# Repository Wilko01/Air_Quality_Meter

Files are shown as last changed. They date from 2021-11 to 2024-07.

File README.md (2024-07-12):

# Air_Quality_Meter
By using a 3D printer in house it is important to understand the health impact like micro particles which are generated in the build process of the products that the 3D printer makes. The SDS011 is used to measure the air quality.

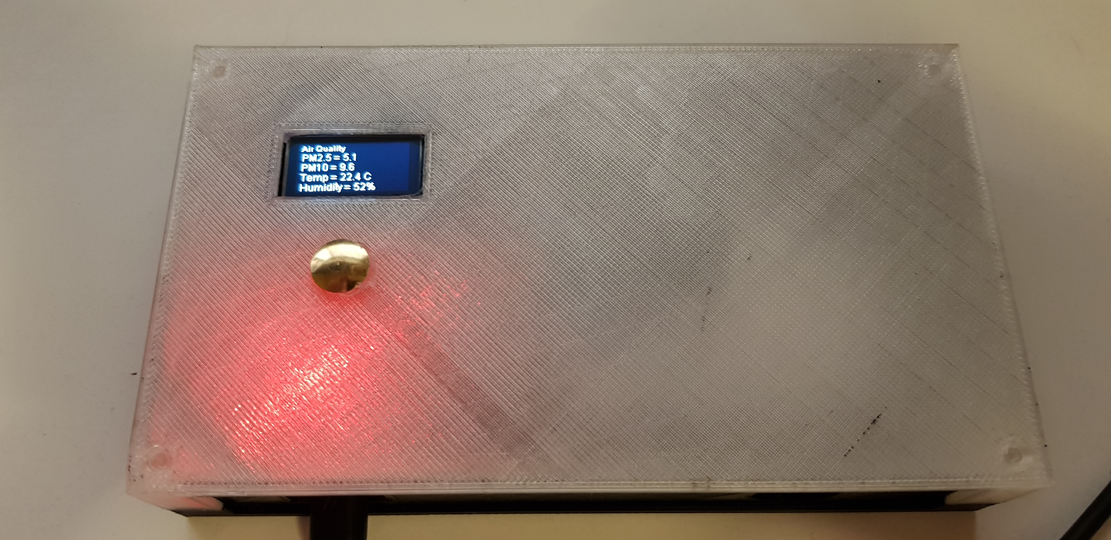
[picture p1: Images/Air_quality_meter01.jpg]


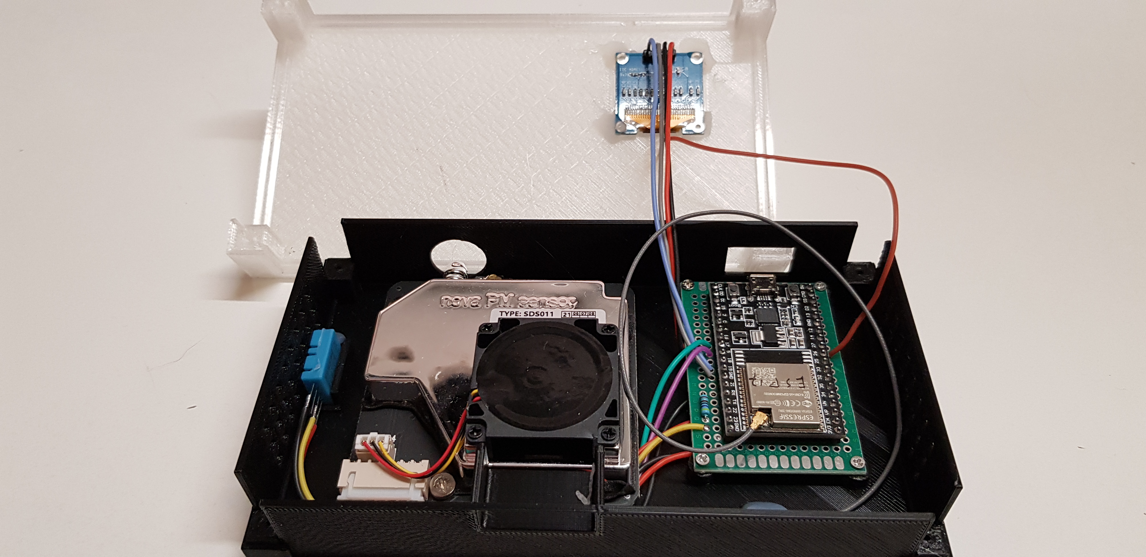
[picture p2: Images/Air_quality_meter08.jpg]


## Description and operation instructions
The SDS011 monitors the air quality by neasuring the 2.5 and 10 um particles in the air. The SDS011 has a lifetime of ~8000 hours, hence the measurement is reduced to periodic measurements. In this case every 10 minutes. The ESP32-WROOM-32U is configured via the ESPHome plugin in Home Assistant. All components are powered via de micro USB connector of the ESP32-WROOM-32U.

 ## Technical description
The SDS011 is connected to the ESP32-WROOM-32D

| SDS101  | ESP32 | SDS1306 | DHT11  | Touch sensor |
| ---|---|---|---|---|
| TX | rx_pin: 16 | | | |
| RX | tx_pin: 17 | | | |
| GND | GND | GND | GND | |
| 5V | 5V | 5V | 5V | |
| | 18 | SDA | | |
| | 19 | SCL | | |
| | 21 | | Signal | |
| | 27 | | | Signal |

### Parts
- 1 x ESP32-WROOM-32U

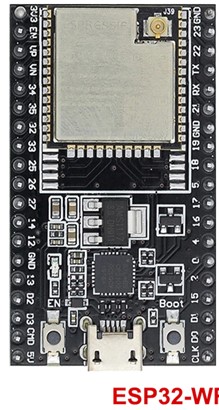
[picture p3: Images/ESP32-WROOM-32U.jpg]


- 1 x 2.4GHz antenna

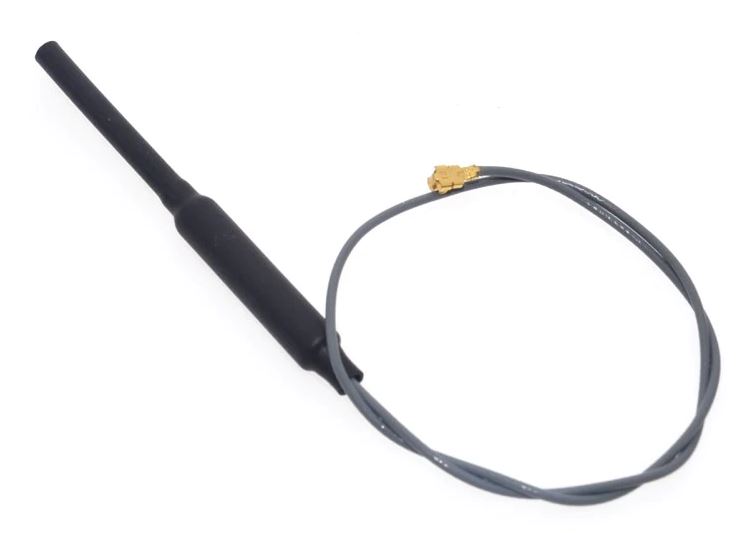
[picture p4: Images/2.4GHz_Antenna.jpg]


- 1 x SDS011

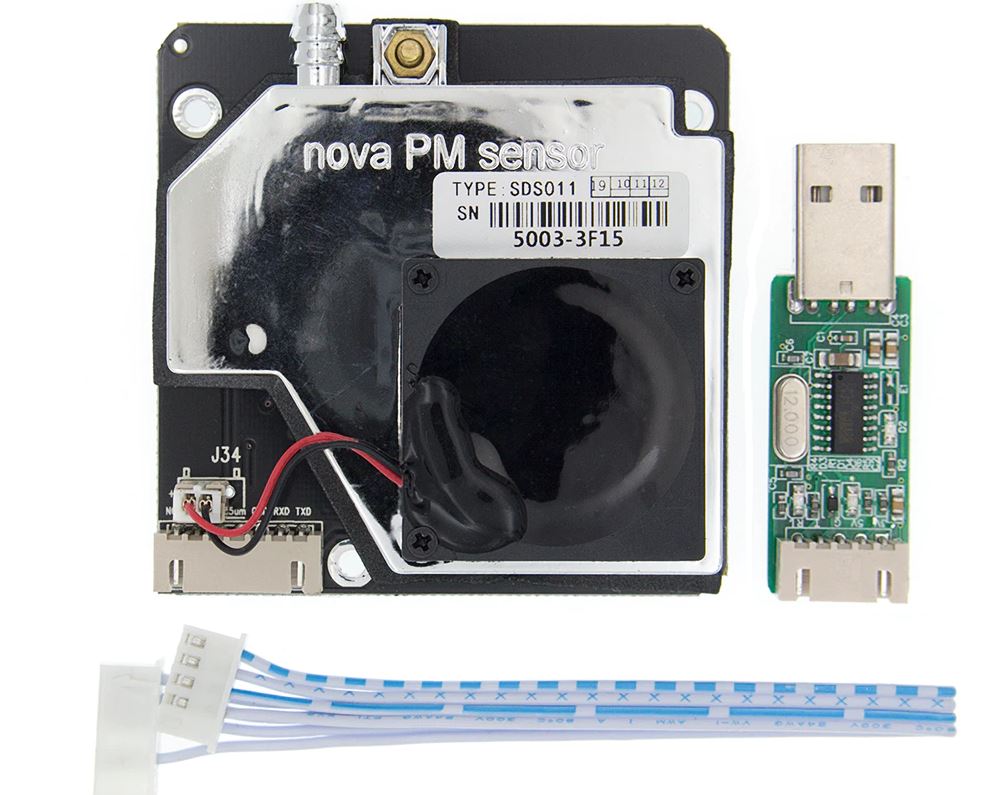
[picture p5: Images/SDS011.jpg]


- 1 x SSD1306 i2C

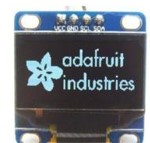
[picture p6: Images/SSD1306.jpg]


- 1 x DHT11

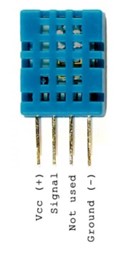
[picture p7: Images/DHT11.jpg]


- 4 x Screws 2.6 x 20 mm
- 1 x thumbtack
- 1 x Micro USB connector

### Schematic overview
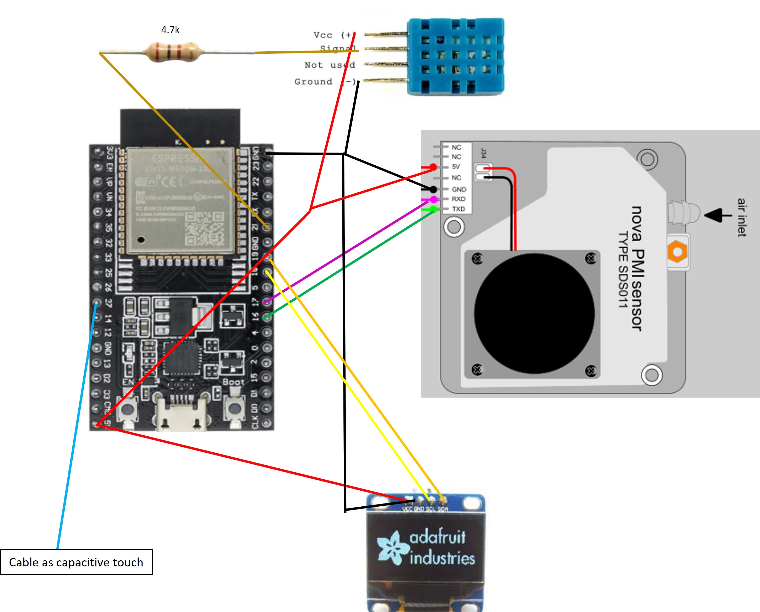
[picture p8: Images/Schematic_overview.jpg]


### ESPHome installation
See the instructions https://github.com/Wilko01/ESPHome  (not listed here)

### ESPHome Configuration in Home Assistant
Create a new device  with this code:
```
# Defining an SDS011 Air Quality Sensor in ESPHome
esphome:
  name: esp17
  platform: ESP32
  board: esp32doit-devkit-v1
  on_boot:
    priority: -100 #lowest priority so start last
    then:
      - lambda: id(display01).turn_off();
#End first code block

# Enable logging
logger:

# Enable Home Assistant API
api:

ota:
  platform: esphome
  password: "4764505ce89048d2422149c83dbc51ca"

wifi:
  ssid: !secret wifi_ssid
  password: !secret wifi_password

  # Enable fallback hotspot (captive portal) in case wifi connection fails
  ap:
    ssid: "Esp17 Fallback Hotspot"
    password: "kWzangCTxyzK"

captive_portal:

# Defining the UART for the SDS011
uart:
  rx_pin: 16
  tx_pin: 17
  baud_rate: 9600

sensor:
  - platform: sds011
    pm_2_5:
      name: "ESP17_Particulates_<2.5µm_Concentration"
      id: pm2_5
    pm_10_0:
      name: "ESP17_Particulates_<10.0µm_Concentration"
      id: pm10_0
    # Set the update interval to balance the accuracy and sensor life
    update_interval: 10min

# Define the temperature and humidity sensor
  - platform: dht
    pin: 21
    temperature:
      name: "ESP17_Temperature"
      id: ESP17_Temperature
    humidity:
      name: "ESP17_Humidity"
      id: ESP17_Humidity
    update_interval: 60s

#specify the connection to the SSD1306
#Connect to the GND and 3,3 but better to 5V
i2c:
  sda: 18
  scl: 19
  scan: true #Will display the i2C address

font:
  - file: 'arial.ttf' #this font file needs to be uploaded to the Home Assistant folder /config/esphome
    id: font1
    size: 10
    
  - file: 'arial.ttf'
    id: font2
    size: 12
    
  - file: 'slkscr.ttf'
    id: font3
    size: 12

esp32_touch:
  setup_mode: false #true shows debug messages in the log and enables to see the intensity of the touch action. 
                   #Make sure to set to false once setup to limit the log spam

binary_sensor:
  - platform: esp32_touch
    name: "ESP17_Touch_Sensor"
    pin: GPIO27
    threshold: 400
    on_release:
      - lambda: id(display01).turn_on();
      - delay: 60s
      - lambda: id(display01).turn_off();

display:
  - platform: ssd1306_i2c
    model: "SSD1306 128x64"
    id: display01
    reset_pin: 0
    address: 0x3C
    contrast: 100%
#Make sure that any comment in the lambda code block is started with // as all
#  code in the block is C++.
    lambda: |-
      it.printf(5, 0, id(font1), "Air Quality");
      if (id(pm2_5).has_state()) {
        it.printf(5, 12, id(font2), "PM2.5 = %.1f", id(pm2_5).state);
      }
      if (id(pm10_0).has_state()) {
        it.printf(5, 25, id(font2), "PM10 = %.1f", id(pm10_0).state);
      }
      if (id(ESP17_Temperature).has_state()) {
        it.printf(5, 38, id(font2), "Temp = %.1f C", id(ESP17_Temperature).state);
      }
      if (id(ESP17_Humidity).has_state()) {
        it.printf(5, 51, id(font2), "Humidity = %.0f%%", id(ESP17_Humidity).state);
      }
#Print the text at column 64 and row 31
#end code

```

### Interface
#### Home Assistant
Home Assistant is connected via the ESPHome integration. The hazardous values for the 2.5um are different from the values of the 10.0um. Therefore two cards are made in the dashboard.

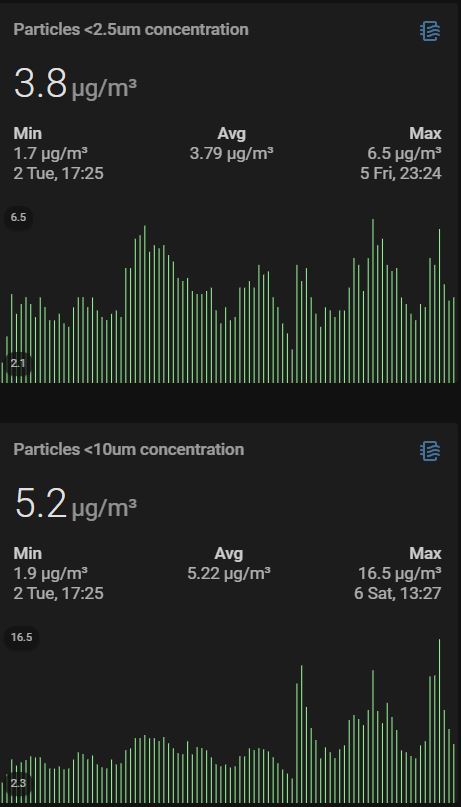
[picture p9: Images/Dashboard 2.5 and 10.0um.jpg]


##### 2.5um card
Create a card in the dashboard of Home Assistant with this code for the 2.5um measurement:
```
type: entities
style:
  .: |
    ha-card {
      --ha-card-box-shadow: none;
      background-color: transparent;
      border-radius: none;

    }
entities:
  - type: custom:mini-graph-card
    entities:
      - entity: sensor.particulates_2_5um_concentration
    icon: mdi:air-filter
    height: 200
    hours_to_show: 96
    more_info: false
    hour24: true
    points_per_hour: 6
    aggregate_func: max
    color_thresholds:
      - value: 0
        color: lightgreen
      - value: 24
        color: green
      - value: 36
        color: yellow
      - value: 48
        color: orange
      - value: 54
        color: red
    line_width: 11
    font_size: 120
    show:
      graph: bar
      average: true
      extrema: true
      name: true
      icon: true
      labels: true
      labels_secondary: true
```

##### 10.0um card
Create a card in the dashboard of Home Assistant with this code for the 10.0um measurement:
```
type: entities
style:
  .: |
    ha-card {
      --ha-card-box-shadow: none;
      background-color: transparent;
      border-radius: none;

    }
entities:
  - type: custom:mini-graph-card
    entities:
      - entity: sensor.particulates_10_0um_concentration
    icon: mdi:air-filter
    height: 200
    hours_to_show: 96
    more_info: false
    hour24: true
    points_per_hour: 6
    aggregate_func: max
    color_thresholds:
      - value: 0
        color: lightgreen
      - value: 34
        color: green
      - value: 51
        color: yellow
      - value: 59
        color: orange
      - value: 76
        color: red
    line_width: 11
    font_size: 120
    show:
      graph: bar
      average: true
      extrema: true
      name: true
      icon: true
      labels: true
      labels_secondary: true

```

### NodeRed
Create a flow to alert when the quality of the air is not in the green area anymore.
```
[{"id":"7c1ab4b.67aba4c","type":"tab","label":"Flow 1","disabled":false,"info":""},{"id":"5170f15d.af318","type":"server-state-changed","z":"7c1ab4b.67aba4c","name":"Air quality 2.5um particles","server":"b64c0ad2.df17f8","version":1,"exposeToHomeAssistant":false,"haConfig":[{"property":"name","value":""},{"property":"icon","value":""}],"entityidfilter":"sensor.particulates_2_5um_concentration","entityidfiltertype":"exact","outputinitially":false,"state_type":"str","haltifstate":"35","halt_if_type":"num","halt_if_compare":"gt","outputs":2,"output_only_on_state_change":false,"for":"","forType":"num","forUnits":"minutes","ignorePrevStateNull":false,"ignorePrevStateUnknown":false,"ignorePrevStateUnavailable":false,"ignoreCurrentStateUnknown":false,"ignoreCurrentStateUnavailable":false,"x":210,"y":380,"wires":[["544cde06.a711d"],[]]},{"id":"544cde06.a711d","type":"function","z":"7c1ab4b.67aba4c","name":"Define email","func":"msg = {\n    payload : \"The air quality is at danger as the amount of 2.5um particles is above 35 particles and colors yelow.\"+ \"\\n\" + \n    \"The amount of 2.5um particles is: \" + msg.payload + \"\\n\" + \n    \"Check the dashboard in Home Assistant\",\n    topic : \"Air quality 2.5um particles alert\",\n};\nreturn msg;\n\n//msg.from = \"HomeAssistant@home.nl\";","outputs":1,"noerr":0,"initialize":"","finalize":"","libs":[],"x":550,"y":360,"wires":[["40967c8c.140c34"]],"info":"Depending on the incoming message ON or OFF, the check will be executed to turn the light with a certain LUX value based on day or night."},{"id":"40967c8c.140c34","type":"e-mail","z":"7c1ab4b.67aba4c","server":"smtp.ziggo.nl","port":"587","secure":false,"tls":true,"name":"wilko@wmmt.nl","dname":"Mail to Wilko@wmmt.nl","x":810,"y":360,"wires":[]},{"id":"dd2ee594.0b6bd8","type":"server-state-changed","z":"7c1ab4b.67aba4c","name":"Air quality 10.0um particles","server":"b64c0ad2.df17f8","version":1,"exposeToHomeAssistant":false,"haConfig":[{"property":"name","value":""},{"property":"icon","value":""}],"entityidfilter":"sensor.particulates_10_0um_concentration","entityidfiltertype":"exact","outputinitially":false,"state_type":"str","haltifstate":"50","halt_if_type":"num","halt_if_compare":"gt","outputs":2,"output_only_on_state_change":false,"for":"","forType":"num","forUnits":"minutes","ignorePrevStateNull":false,"ignorePrevStateUnknown":false,"ignorePrevStateUnavailable":false,"ignoreCurrentStateUnknown":false,"ignoreCurrentStateUnavailable":false,"x":210,"y":480,"wires":[["52896b9f.10ef64"],[]]},{"id":"52896b9f.10ef64","type":"function","z":"7c1ab4b.67aba4c","name":"Define email","func":"msg = {\n    payload : \"The air quality is at danger as the amount of 10um particles is above 50 particles and colors yelow.\"+ \"\\n\" + \n    \"The amount of 10.0um particles is: \" + msg.payload + \"\\n\" + \n    \"Check the dashboard in Home Assistant\",\n    topic : \"Air quality 10.0um particles alert\",\n};\nreturn msg;\n\n//msg.from = \"HomeAssistant@home.nl\";","outputs":1,"noerr":0,"initialize":"","finalize":"","libs":[],"x":550,"y":460,"wires":[["c682708.937569"]],"info":"Depending on the incoming message ON or OFF, the check will be executed to turn the light with a certain LUX value based on day or night."},{"id":"c682708.937569","type":"e-mail","z":"7c1ab4b.67aba4c","server":"smtp.ziggo.nl","port":"587","secure":false,"tls":true,"name":"wilko@wmmt.nl","dname":"Mail to Wilko@wmmt.nl","x":810,"y":460,"wires":[]},{"id":"c10ecf40.1e4ad","type":"comment","z":"7c1ab4b.67aba4c","name":"Check air quality by measuring the 2.5 and 10.0 um particles","info":"","x":300,"y":300,"wires":[]},{"id":"b64c0ad2.df17f8","type":"server","name":"Home Assistant","legacy":false,"addon":true,"rejectUnauthorizedCerts":true,"ha_boolean":"y|yes|true|on|home|open","connectionDelay":true,"cacheJson":true}]
```

### Testing
Create a dashboard in Home Assistant and see the measurements come in. Depending on the measurement interval this can take some time.

## 3D printer files
It all started by measuring the air quality when printing, so the 3D printer files must be included in this project:
- [3D files include the Sketchup make file as well as the 3D print files .STL](/3D_Printer_Files)
- [Thingiverse](https://www.thingiverse.com/thing:5135259)

### Information
- [ESPHome syntax](https://esphome.io)
- [Air quality sensor with ESPHome](https://cyan-automation.medium.com/creating-an-air-quality-sensor-using-an-sds011-and-esphome-7305f764f6f5)
- [ESPHome syntax for writing text in the yaml file to be printed on a LCD](https://esphome.io/components/display/index.html#display-printf)

Generic
- [Markdown Cheat Sheet](https://www.markdownguide.org/cheat-sheet/)

### Problems
..

### Wishlist
..

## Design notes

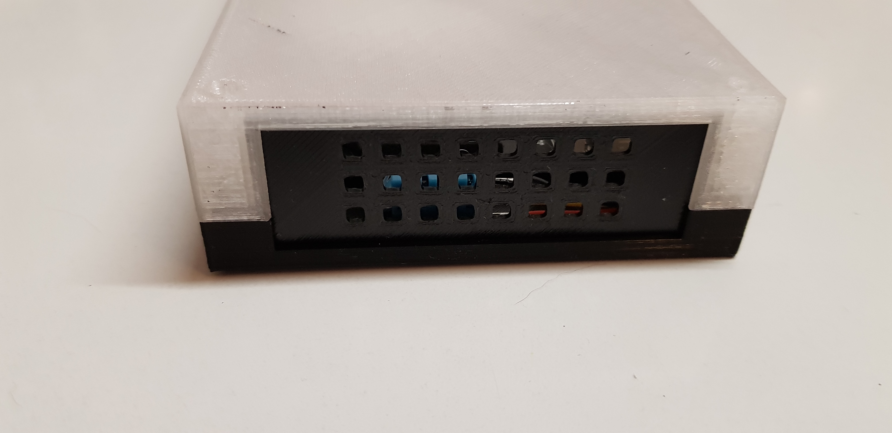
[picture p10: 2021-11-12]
Images/Air_quality_meter06.jpg

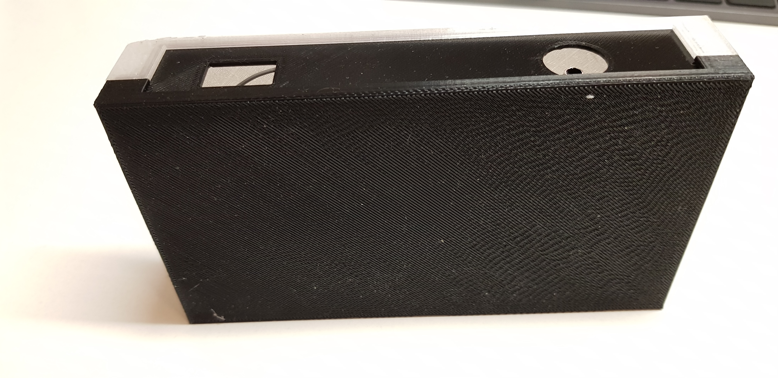
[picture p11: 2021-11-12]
Images/Air_quality_meter04.jpg

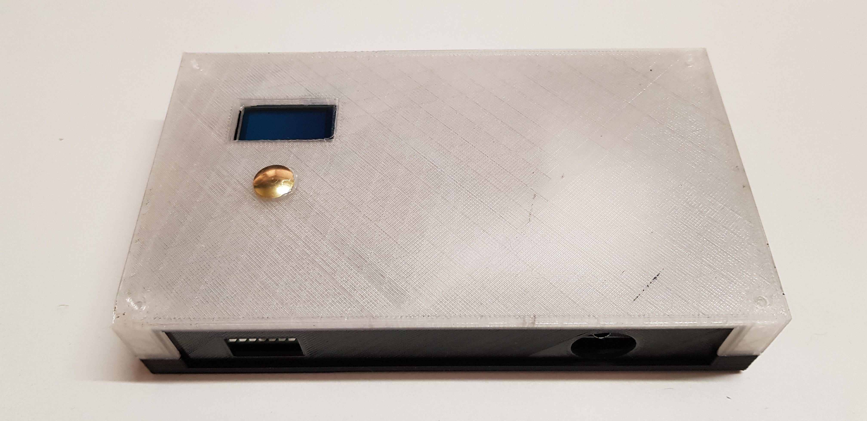
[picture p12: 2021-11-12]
Images/Air_quality_meter02.jpg

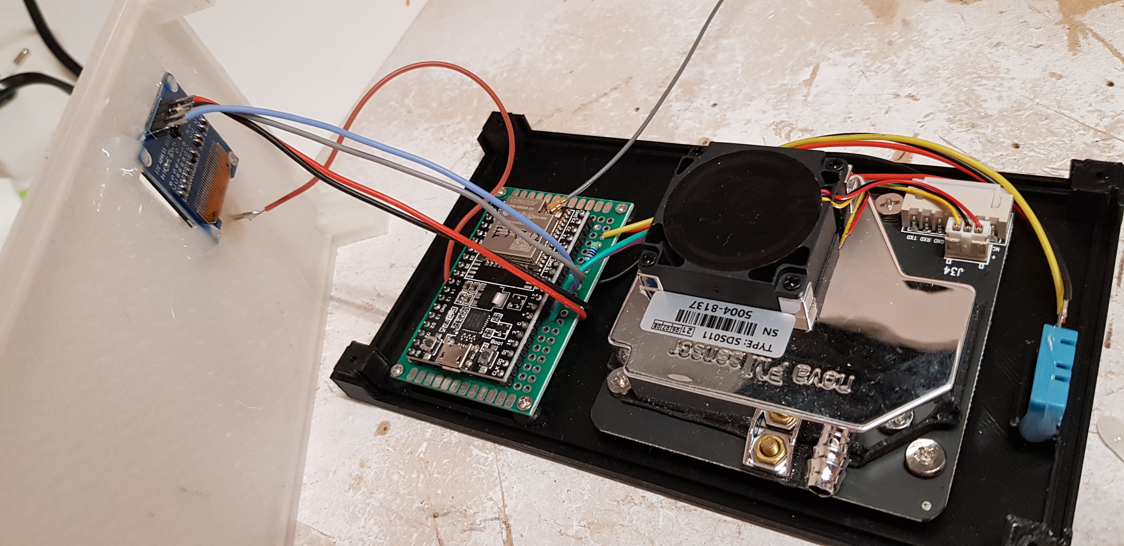
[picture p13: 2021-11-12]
Images/Air_quality_meter07.jpg

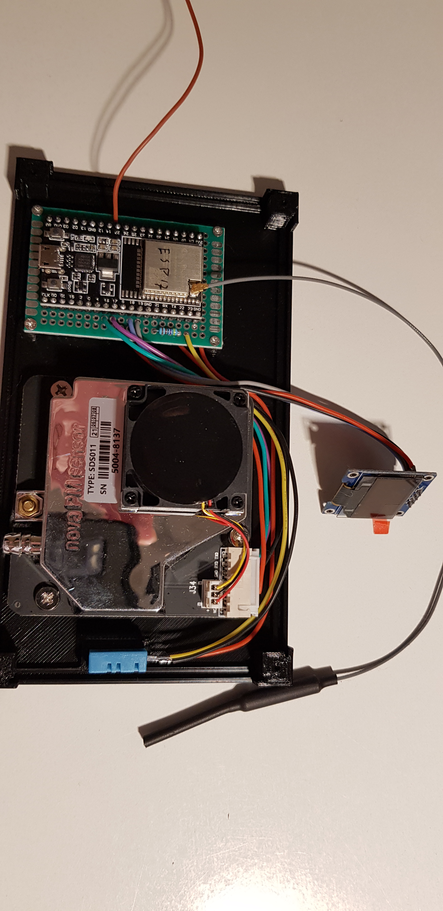
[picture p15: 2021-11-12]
Images/Air_quality_meter10.jpg

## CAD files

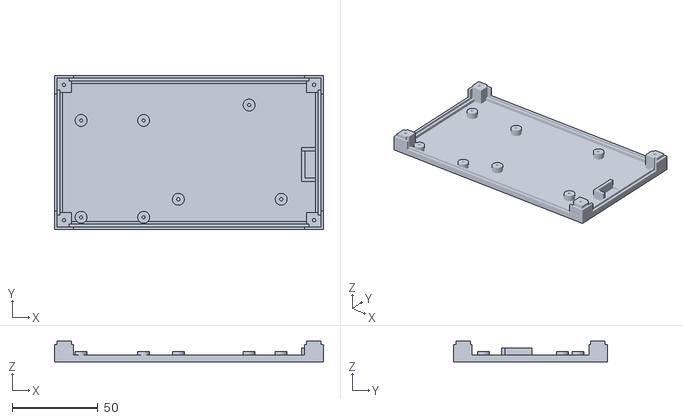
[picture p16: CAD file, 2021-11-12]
3D_Printer_Files/Air quality SDS011 Box - back.stl
157.0 x 90.0 x 12.0

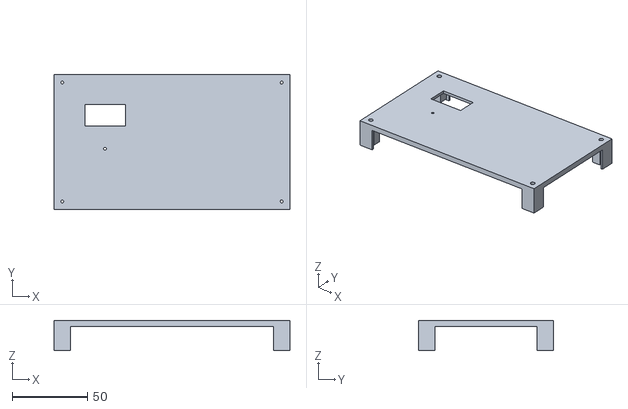
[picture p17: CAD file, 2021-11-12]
3D_Printer_Files/Air quality SDS011 Box - front.stl
157.0 x 90.0 x 20.0

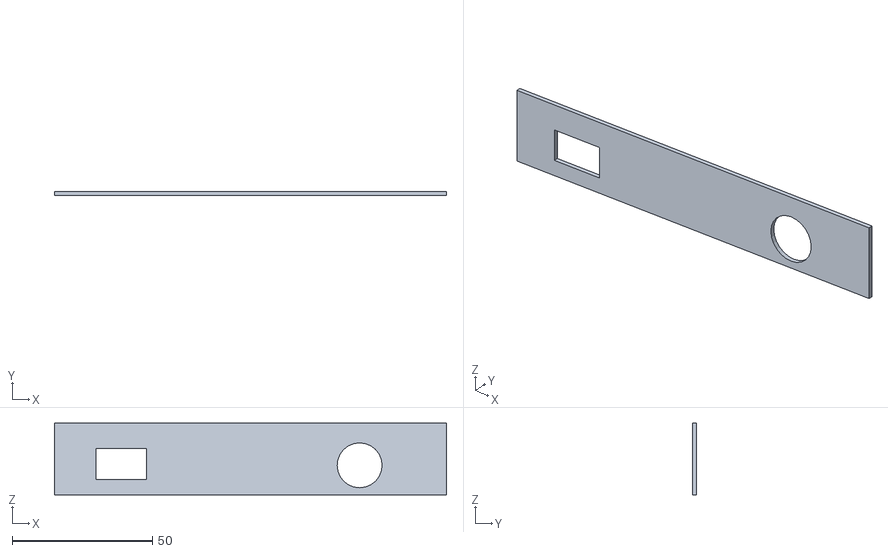
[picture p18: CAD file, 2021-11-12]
3D_Printer_Files/Air quality SDS011 Box - side bottom.stl
139.6 x 1.50 x 25.5

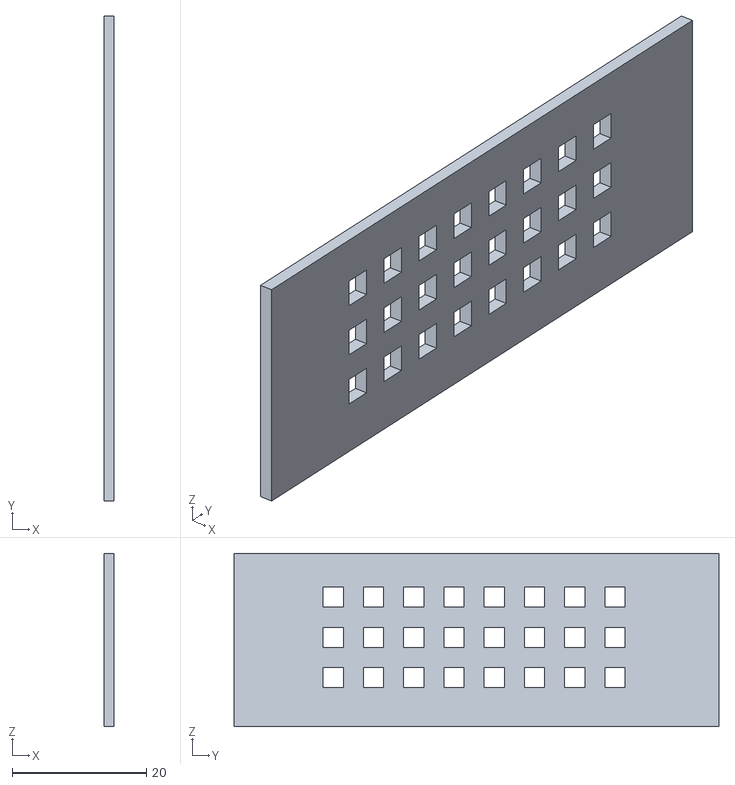
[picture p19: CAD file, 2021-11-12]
3D_Printer_Files/Air quality SDS011 Box - side right.stl
1.50 x 72.3 x 25.8

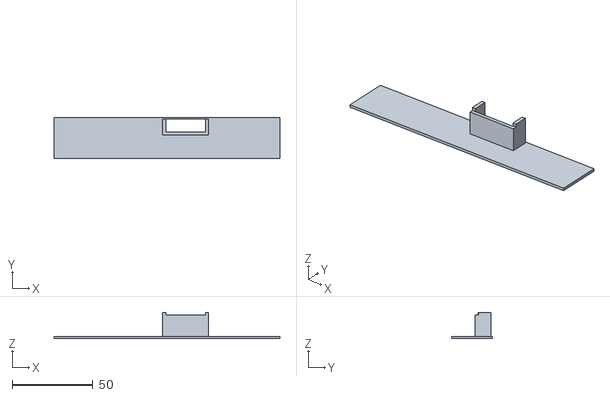
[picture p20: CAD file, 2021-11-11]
3D_Printer_Files/Air quality SDS011 Box - side top.stl
139.8 x 25.5 x 16.3

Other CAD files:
3D_Printer_Files/Air quality SDS011 box.skp
3D_Printer_Files/Air_quality_SDS011_box.skp

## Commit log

2021-11-06 Added NodeRed flow and dashboard
2021-11-07 Added SSD1306 display and touch sensor
2021-11-08 Added 3D printer files and updated code DHT11
    [Air quality SDS011 box 01.skp, Template 01.stl]
2021-11-08 Updated readme and 3D files
    [Air quality SDS011 Box - back 01.stl, Air quality SDS011 Box - front 01.stl, Air quality SDS011 Box - side bottom 01.stl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]
2021-11-08 added antenna to readme
2021-11-08 Made links to 3D files
    [Air quality SDS011 Box - back.stl, Air quality SDS011 Box - front.stl, Air quality SDS011 Box - side bottom.stl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]
2021-11-08 update links
    [Air_quality_SDS011_box.skp]
2021-11-08 Updated links
    [Air quality SDS011 box.skp]
2021-11-11 added touchpin to the md file
    [Air quality SDS011 Box - back.stl, Air quality SDS011 Box - front.stl, Air quality SDS011 Box - side bottom.stl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]
2021-11-12 Made small 3D modifications and added pictures
    [Air quality SDS011 Box - back.stl, Air quality SDS011 Box - front.stl, Air quality SDS011 Box - side bottom.stl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]
2021-11-12 updated 3D files
    [Air quality SDS011 Box - back.stl]
